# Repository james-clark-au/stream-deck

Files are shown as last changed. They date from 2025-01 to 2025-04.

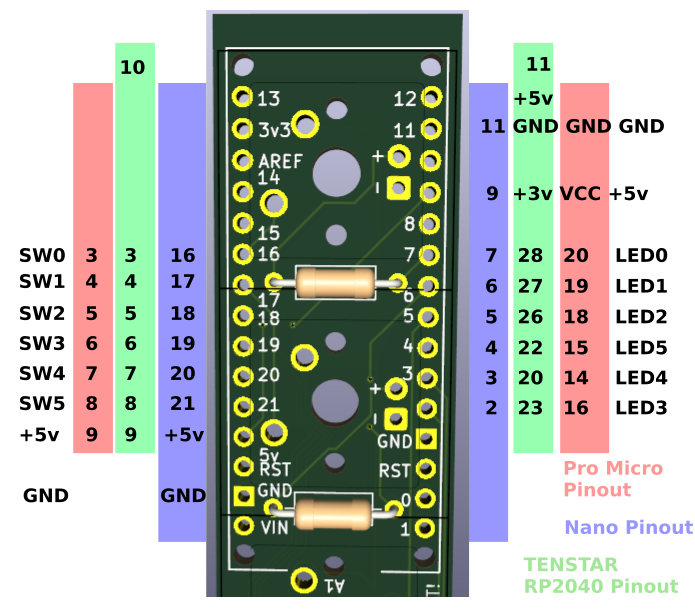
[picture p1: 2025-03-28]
pcb/pinouts.png

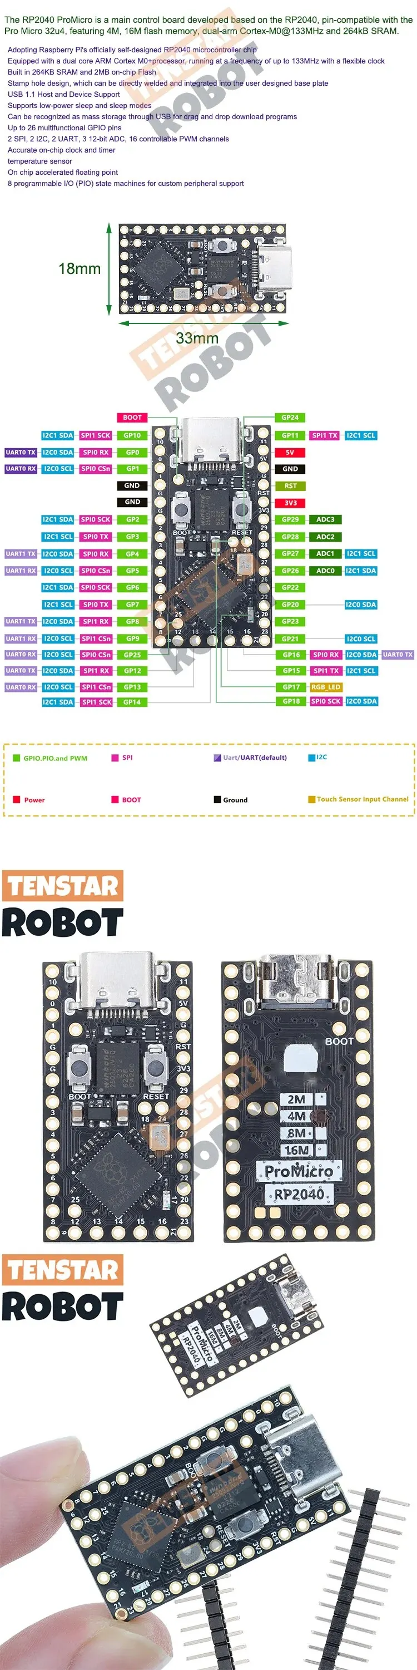
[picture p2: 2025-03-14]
pcb/tenstar-rp2040-pro-micro.webp

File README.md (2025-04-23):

# James Neko's Stream Deck

I made my own 6-key macropad for streaming out of an old mechanical key 'switch tester' I had! In doing so, I designed and had my very first PCB manufactured!

There's code here for both Arduino C++ _(Using a Nano, and relying on a Perl [lazy-serial-daemon](https://github.com/james-clark-au/lazy-serial-daemon) plugin to respond to the keys)_ and CircuitPython for a TENSTAR RP2040 board that uses the Pro Micro form factor.

There's also some 3D printing files - one for the partial enclosure I adapted my switch tester with, one for a full housing for it.

## Configuration

Presuming you're using the RP2040 / CircuitPython version, you might want some help on configuring it.

### Getting the CIRCUITPY drive to show up

Because it's a bit annoying to see the virtual USB drive show up all the time, I configure mine to hide it by default. This is done by editing `boot.py` and changing the line `HIDE_CIRCUITPY_DRIVE = False` to `True`. When this is set to `True`, the device will only show up as two USB Serial ports and one USB HID (Keyboard/Mouse) device.

To get it to show up as a USB Mass Storage device again, so you can edit the onboard files, hold down Key 0 - the one closest to the cable - as you plug it in. You can let go once the drive shows up.

On the CIRCUITPY drive, the two files you want to edit are `boot.py` for the setting above, and `code.py` to change your keys' behaviours. If you're on a Microsoft system you _might_ need a text editor smarter than NOTEPAD.EXE.

### Editing the key mapping

At the top of `code.py` you should see the current behaviours assigned to each key. The example configuration defines two modes that can be switched between:-

```python
config_mode0 = {
  0: RadioButton(key=(Keycode.GUI, Keycode.Q), group=(0, 1, 2)),
  1: RadioButton(key=(Keycode.GUI, Keycode.R), group=(0, 1, 2)),
  2: RadioButton(key=(Keycode.GUI, Keycode.S), group=(0, 1, 2)),
  3: SimpleButton(key=Keycode.RIGHT_SHIFT),
  4: SpamButton(key=MouseLeft(), delay_ms=30),
  5: ModeSwitch(),
}
config_mode1 = {
  0: RadioButtonWithHold(key=(Keycode.CONTROL, Keycode.ALT, Keycode.SHIFT, Keycode.ONE), key_when_held="Hello", group=(0, 1)),
  1: RadioButtonWithHold(key=(Keycode.CONTROL, Keycode.ALT, Keycode.SHIFT, Keycode.TWO), key_when_held="World", group=(0, 1)),
  2: MomentaryButton(key_on=(Keycode.GUI, Keycode.V), key_off=(Keycode.GUI, Keycode.V), led_initial=False),
  3: ToggleButton(key_on=(Keycode.GUI, Keycode.V), key_off=(Keycode.GUI, Keycode.V), led_initial=True),
  4: ToggleButton(key_on="Bed goes up", key_off="Bed goes down"),
  5: ModeSwitch(),
}
```

Slightly below that, those 'modes' are loaded with the line:-
```
deck = StreamDeck(lazy, [config_mode0, config_mode1])
```

You'll only need to modify that if you want to play with lots of different modes; if you just want the same behaviour for each key all the time, edit `config_mode0` and don't worry about anything else.

You'll see that after each key number 0..5 is the name of a Python class and some parameters in parentheses. Don't forget the comma at the end. The parameters change depending on which class you use, but most take a `key=` parameter, or two `key_on=` and `key_off=` parameters. The key can be defined in a few different ways, but more on that later.

Here are the different behaviours you can use (defined in `Behaviours.py`):-

#### SimpleButton(key=, light_while_pressed=True)

The most basic. Sends the key down event for your `key` when you press the button, sends the key up event when you release it.

`light_while_pressed` controls what the LED should do - turn on as you press the button (True), or be on all the time (False).

#### ToggleButton(key_on=, key_off=, led_initial=False)

This button remembers whether it's 'on' or 'off', and starts 'off' (`led_initial`).

It does a quick tap of `key_on` when you turn it on, and a quick tap of `key_off` (which can be the same as `key_on`) when you push the button and turn the LED off.

You could use this for e.g. a 'mute mic' button, so the LED indicates whether you've muted or unmuted it -- assuming it starts in the right state. If you want it to accurately reflect your mute state, you'd need to write extra code for your computer.

#### MomentaryButton(key_on=, key_off=, led_initial=False)

This button defaults to being 'on' or 'off' (depending on how you set `led_initial`), and becomes 'off' or 'on' only while held down.

Like the ToggleButton, it does a quick tap of `key_on` when you turn it on, and a quick tap of `key_off` (which can be the same as `key_on`) when you push the button and turn the LED off.

You could use this for e.g. a 'push to talk' button, or a 'push to mute' button, so that it sends the keyboard shortcut to mute/unmute when you start holding it, and does the same thing when you release it.

#### RadioButton(key=, group=())

This button works a little like the SimpleButton, sending a key down event when you push it and sending the key release event when you let go. What changes here is the LED - it starts off, and when it is pushed it switches itself on - and all the other RadioButtons in the same group off.

You could use this for switching scenes in OBS - set the `key=` for each button to some complicated shortcut key you set in OBS, and now as you switch between them, the relevant light will stay on! Be sure to set the `group=` parameter to the numbers of each other RadioButton - e.g. the whole deck would be `group=(0,1,2,3,4,5)`.

You _can_ make the LEDs update if you switch scenes from clicking around in OBS, but that will require a program running on your computer to connect to OBS and the USB Serial Port the Deck exposes.

#### RadioButtonWithHold(key=, key_when_held=, group=())

Exactly the same as RadioButton, but:-

- It only taps the `key` when released, if you tap the button.
- If you hold the button down longer than a second, it instead taps the `key_when_held`, and begins flashing its LED instead of the LED being on continuously.

This way you get an extra second layer of possible radio buttons!

#### SpamButton(key=, light_while_pressed=True, delay_ms=20)

This button repeatedly taps the `key` for as long as you hold it.

#### ModeSwitch(prev=False, light_while_pressed=True)

This button switches to the next mode defined in the config, or if `prev=True`, the previous mode. The lights will briefly flash to indicate you've changed modes.

### Key definitions

There are multiple ways to specify what kind of key you want to simulate on a button push. Most of these reference `Keycode` definitions that come from the [adafruit_hid library](https://docs.circuitpython.org/projects/hid/en/latest/api.html#adafruit_hid.keycode.Keycode)

The simplest and most straightforward is a single key on your keyboard, such as `Keycode.RIGHT_SHIFT`, `Keycode.Q`, or `Keycode.F1`.

Most keyboard shortcuts you might want to use though, are going to be complex ctrl-alt-shift-super kind of chords that you wouldn't normally type - because you want to use some global shortcut that doesn't conflict with any application shortcuts. To do these, put a list of Keycode values in parentheses, modifiers first, then the key you want to trigger last. For example, `(Keycode.CONTROL, Keycode.ALT, Keycode.SHIFT, Keycode.ONE)`. The library refers to your Super or Command or MICROSOFT WINDOWS™ LOGO® key as `Keycode.GUI`.

If you want to get silly, you can also put a plain-text string for your `key=` value, such as `"Let's circle back and align our goals on this later."`. The code will type out the message.

Finally, it's possible to 'press' mouse buttons in place of keys. `MouseLeft()`, `MouseRight()` and `MouseMiddle()` are set up if you need to do this for some strange reason. Try it with `SpamButton`!

## Errata

When laying out the PCB, I decided to grab the closer A6 and A7 inputs for switches 4 and 5, but I forgot that the Arduino Nano _doesn't let you do digital input on those pins_. I ended up using bodge wires from A0 and A1 to A6 and A7 to let me still easily read the switch status.

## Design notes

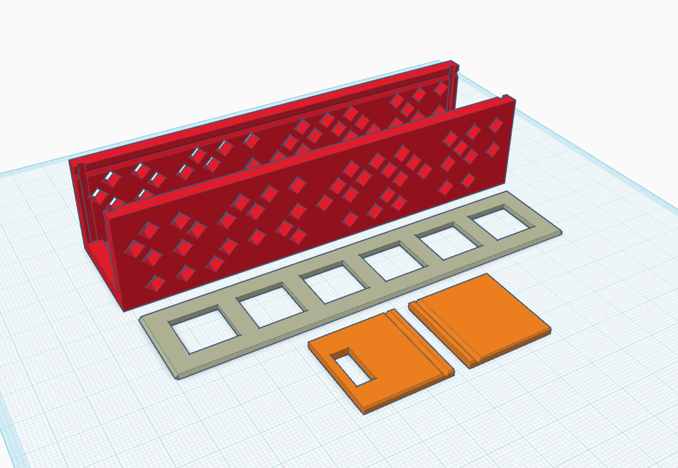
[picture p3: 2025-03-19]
stl/stream-deck-full-exploded.png

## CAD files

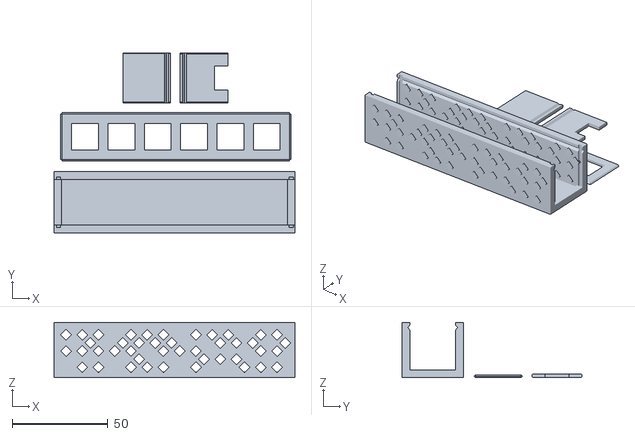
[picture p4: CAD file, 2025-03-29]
stl/stream-deck-full-exploded.stl
126.0 x 94.0 x 29.0

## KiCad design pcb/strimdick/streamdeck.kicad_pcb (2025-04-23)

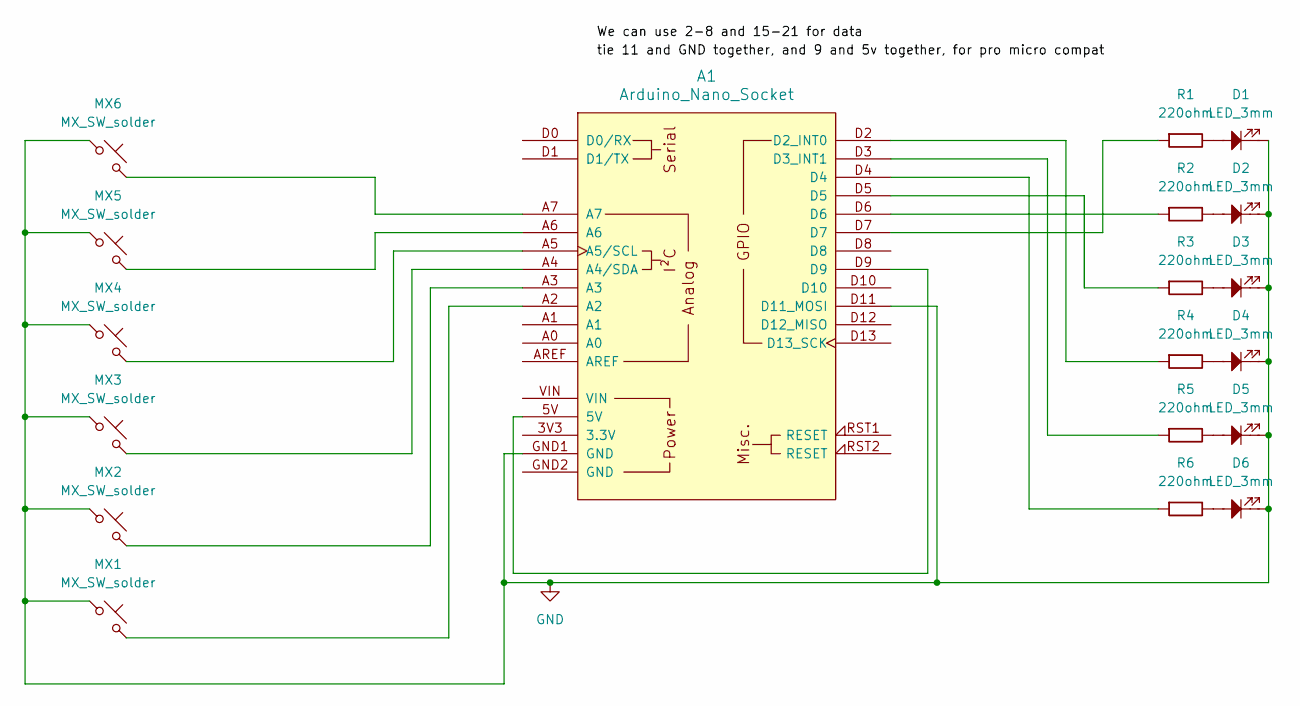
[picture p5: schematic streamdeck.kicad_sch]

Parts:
A1: Arduino_Nano_Socket
D1, D2, D3, D4, D5, D6: LED_3mm; LED_MX_3mm
MX1, MX2, MX3, MX4, MX5, MX6: MX_SW_solder; SW_MX_1u
R1, R2, R3, R4, R5, R6: 220ohm; R_Axial_DIN0207_L6.3mm_D2.5mm_P10.16mm_Horizontal

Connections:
GND: A1.D11 (D11_MOSI), A1.GND1 (GND), D1.1, D2.1, D3.1, D4.1, D5.1, D6.1, MX1.1, MX2.1, MX3.1, MX4.1, MX5.1, MX6.1
unnamed: A1.A4 (A4/SDA), MX3.2
unnamed: A1.A5 (A5/SCL), MX4.2
unnamed: A1.D2 (D2_INT0), R4.1
unnamed: A1.D3 (D3_INT1), R5.1
unnamed: A1.5V, A1.D9
unnamed: A1.A2, MX1.2
unnamed: A1.A3, MX2.2
unnamed: A1.A6, MX5.2
unnamed: A1.A7, MX6.2
unnamed: A1.D4, R6.1
unnamed: A1.D5, R3.1
unnamed: A1.D6, R2.1
unnamed: A1.D7, R1.1
unnamed: D1.2, R1.2
unnamed: D2.2, R2.2
unnamed: D3.2, R3.2
unnamed: D4.2, R4.2
unnamed: D5.2, R5.2
unnamed: D6.2, R6.2

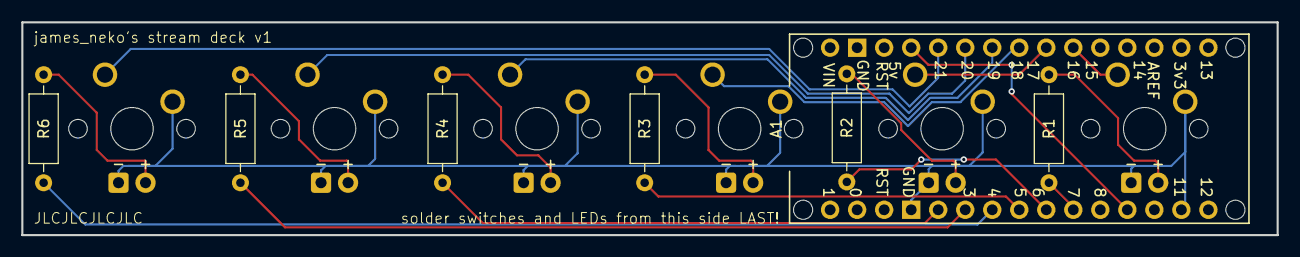
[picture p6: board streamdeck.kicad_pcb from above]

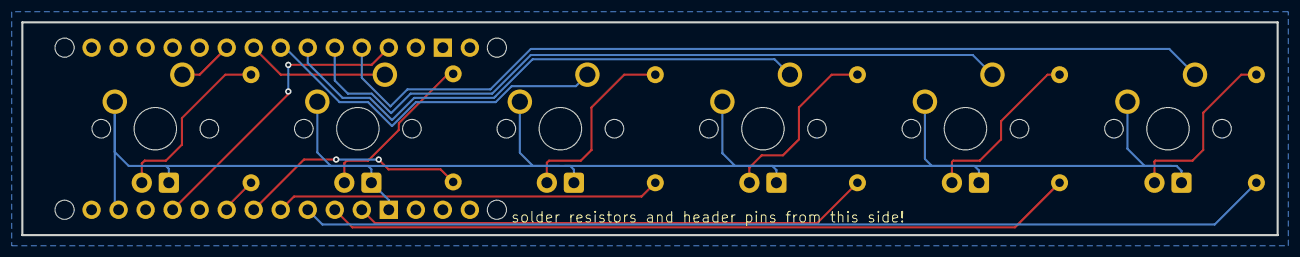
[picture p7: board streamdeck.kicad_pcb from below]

Board: 2 copper layers, 118.0 x 20.0 mm, 19 parts (12 on the bottom side), 20 nets.

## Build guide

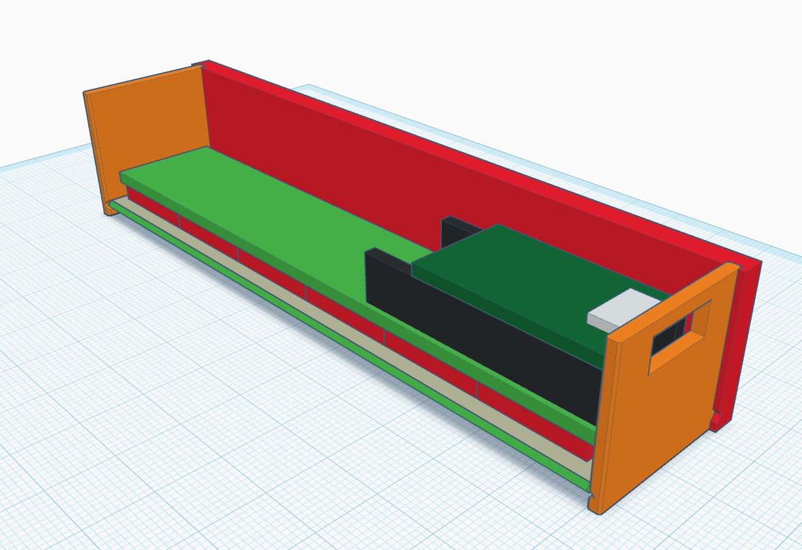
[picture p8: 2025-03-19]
stl/stream-deck-full-assembled.png

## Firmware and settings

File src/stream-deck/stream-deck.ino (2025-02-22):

#include "globals.h"
#include "commands.h"


char read_saved_script(size_t pos) {
  return saved.readChar(pos);
}


void setup() {
  register_commands();
  Serial.begin(BAUD_RATE);

  saved.init();
  lazy.run_script(&read_saved_script);
  cmd_eyecatch(nullptr);
  Serial.println(F("\nOK READY"));
}


void loop() {
  lazy.loop();
  blinky.loop();
  for (int i = 0; i < NUM_LEDS; ++i) {
    leds[i].loop();
  }
  for (int i = 0; i < NUM_KEYS; ++i) {
    PushButton::PressState pushed = keys[i].loop();
    if (pushed == PushButton::PRESSED) {
      led_only(i);
    } else if (pushed == PushButton::RELEASED) {
      Serial.print(F("INPUT KEY "));
      Serial.print(i);
      Serial.println(F(" CLICKED"));
    } else if (pushed == PushButton::HELD && keys[i].lastHoldTime() > 1000) {
      keys[i].cancel();
      Serial.print(F("INPUT KEY "));
      Serial.print(i);
      Serial.println(F(" HELD"));
      leds[i].blink(1000);
      leds[i].set(LOW);  // Make sure it starts off
    }
  }
  if (heart.enabled() && ! heart.beating()) {
    heart.setEnabled(false);
    cmd_clear(nullptr);
  }

  delay(1);
}

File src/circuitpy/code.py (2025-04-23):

import microcontroller
# adafruit_hid is a separate library you need to get from the circuitpy site and drop in lib/
from adafruit_hid.keycode import Keycode
from adafruit_hid.mouse import Mouse

from BlinkyLed import BlinkyLed
from PushButton import PushButton, PushState
from Heartbeat import Heartbeat
from LazySerial import LazySerial
from StreamDeck import StreamDeck
from Behaviours import *
from Keeb import MouseLeft, MouseRight, MouseMiddle


############################################ CONFIG ################################################
# Here we define what we actually want each key to do. Associate keys 0-5 with a Behaviour,
# various types defined in Behaviours.py. Values for 'key' parameters can be a Keycode value,
# from https://docs.circuitpython.org/projects/hid/en/latest/api.html#adafruit_hid.keycode.Keycode
# or a Tuple of several Keycode values for a chorded sequence, or a string literal for some text
# to type. None should also work, if you just want a key to send a serial console message.
####################################################################################################
config_mode0 = {
  0: RadioButton(key=(Keycode.GUI, Keycode.Q), group=(0, 1, 2)),
  1: RadioButton(key=(Keycode.GUI, Keycode.R), group=(0, 1, 2)),
  2: RadioButton(key=(Keycode.GUI, Keycode.S), group=(0, 1, 2)),
  3: SimpleButton(key=Keycode.RIGHT_SHIFT),
  4: SpamButton(key=MouseLeft(), delay_ms=30),
  5: ModeSwitch(),
}
config_mode1 = {
  0: RadioButtonWithHold(key=(Keycode.CONTROL, Keycode.ALT, Keycode.SHIFT, Keycode.ONE), key_when_held="Hello", group=(0, 1)),
  1: RadioButtonWithHold(key=(Keycode.CONTROL, Keycode.ALT, Keycode.SHIFT, Keycode.TWO), key_when_held="World", group=(0, 1)),
  2: MomentaryButton(key_on=(Keycode.GUI, Keycode.V), key_off=(Keycode.GUI, Keycode.V), led_initial=False),
  3: ToggleButton(key_on=(Keycode.GUI, Keycode.V), key_off=(Keycode.GUI, Keycode.V), led_initial=True),
  4: ToggleButton(key_on="Bed goes up", key_off="Bed goes down"),
  5: ModeSwitch(),
}

############################################ GLOBALS ###############################################
lazy = LazySerial()
blinky = BlinkyLed(microcontroller.pin.GPIO17, 500)
blinky.blink()
heart = Heartbeat(10000)
deck = StreamDeck(lazy, [config_mode0, config_mode1])


######################################### SERIAL COMMANDS ##########################################
# These are commands you can use on the serial interface (e.g. /dev/ttyACM1) to receive key input
# and control LEDs yourself via a program on the host, if you choose.
# Not to be confused with the CircuitPython REPL that also exists (on e.g. /dev/ttyACM0)
####################################################################################################
def cmd_ohai(lazy, args):
  lazy.say("OHAI circuitpy-stream-deck 1.0")
lazy.register("OHAI", cmd_ohai)

def cmd_eyecatch(lazy, args):
  deck.eyecatch()
  lazy.say("OK EYECATCH")
lazy.register("EYECATCH", cmd_eyecatch)

def cmd_clear(lazy, args):
  deck.set_leds(False)
  lazy.say("OK CLEAR")
lazy.register("CLEAR", cmd_clear)

def usage_led(lazy):
  lazy.say("ERR Usage: LED <num> (ON|OFF|ONLY|BLINK)")
  
def cmd_led(lazy, args):
  if len(args) == 0:
    return usage_led(lazy)
  num = 0
  try:
    num = int(args.pop(0))
  except ValueError:
    return usage_led(lazy)
  if num < 0 or num >= len(deck.leds):
    lazy.say("ERR num must be 0..^{}".format(len(deck.leds)))
    return
  if len(args) == 0:
    return usage_led(lazy)
  
  verb = args.pop(0).upper()
  if verb == "OFF":
    deck.leds[num].off()
    lazy.say("OK LED {} {}".format(num, verb))
  elif verb == "ON":
    deck.leds[num].on()
    lazy.say("OK LED {} {}".format(num, verb))
  elif verb == "ONLY":
    deck.set_only_led(num)
    lazy.say("OK LED {} {}".format(num, verb))
  elif verb == "BLINK":
    deck.leds[num].blink()
    lazy.say("OK LED {} {}".format(num, verb))
  else:
    return usage_led(lazy)
lazy.register("LED", cmd_led)

def cmd_heartbeat(lazy, args):
  if len(args) == 0:
    heart.beat()
    lazy.say("OK HEARTBEAT")
    return
  verb = args.pop(0).upper()
  if verb == "ON":
    heart.set_enabled(True)
    lazy.say("OK HEARTBEAT ON")
  elif verb == "OFF":
    heart.set_enabled(False)
    lazy.say("OK HEARTBEAT OFF")
  else:
    heart.beat()
    lazy.say("OK HEARTBEAT")
lazy.register("HEARTBEAT", cmd_heartbeat)

def usage_mode():
  lazy.say("ERR Usage: MODE <num>")
def cmd_mode(lazy, args):
  if len(args) == 0:
    return usage_led(lazy)
  num = 0
  try:
    num = int(args.pop(0))
  except ValueError:
    return usage_led(lazy)
  if num < 0 or num >= len(deck.modes):
    lazy.say("ERR num must be 0..^{}".format(len(deck.modes)))
    return
  lazy.say("OK MODE {}".format(num))
  deck.set_mode(num)
lazy.register("MODE", cmd_mode)


############################################# MAIN LOOP ############################################
print("Starting main loop!")
lazy.init()
deck.eyecatch()

while True:
  deck.loop()
  lazy.loop()
  blinky.loop()
  if heart.enabled() and not heart.beating():
    print("Heartbeat stopped, clearing LEDs!")
    heart.set_enabled(False)
    deck.set_leds(False)

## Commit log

2025-01-29 First bumbling
    [strimdick.kicad_pcb, strimdick.kicad_sch]
2025-01-29 Okay, got the schematic done, and a basic layout with things all stacked up, it's a bit tight
    [strimdick.kicad_pcb, strimdick.kicad_sch]
2025-01-29 Make Design Rules Checker happy
    [strimdick.kicad_pcb]
2025-01-29 Routing, some silkscreen instructions.
    [strimdick.kicad_pcb, strimdick.kicad_sch]
2025-01-29 trying this 'add fill' thing
    [strimdick.kicad_pcb, strimdick.kicad_sch]
2025-01-29 ignore gerber output
2025-01-29 Add JLC text
    [strimdick.kicad_pcb]
2025-02-12 LED control
2025-02-15 3D model to add underneath my switch tester
    [strim-dick-extender.stl]
2025-02-16 First cut of saving to EEPROM.
2025-02-17 Add pin accessor.
2025-02-17 Fix saved script loading!
    [commands.h]
2025-02-22 fix: led sometimes cleared mistakenly
2025-02-22 Implement heartbeat to switch off if we lose connection to LSD
2025-03-14 pinout of this TENSTAR RP2040 board I'm using
2025-03-14 CircuitPy code
2025-03-14 LazySerial first cut
2025-03-18 Update pin
2025-03-18 Extend BlinkyLed to use as our main LED abstraction
2025-03-19 STL model for full housing
    [strim-dick-full-exploded.stl]
2025-03-20 add LED command
2025-03-27 fix bloody index out of bounds error crashing the code
    [Behaviours.py, StrimDick.py, code.py]
2025-03-27 fix: PushButton hold time
    [PushButton.py]
2025-03-27 fix: forgot to give the leds a tick
    [Behaviours.py, StrimDick.py]
2025-03-27 Implement mode switching
2025-03-29 Extend the USB hole down.
    [strim-dick-full-exploded.stl]
